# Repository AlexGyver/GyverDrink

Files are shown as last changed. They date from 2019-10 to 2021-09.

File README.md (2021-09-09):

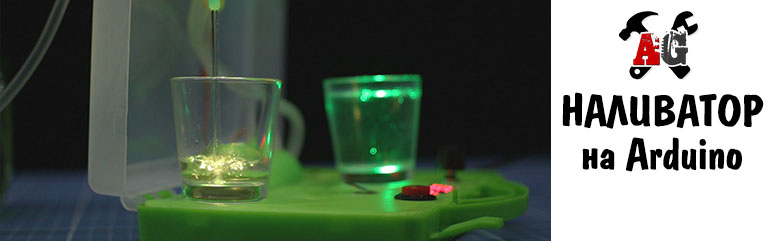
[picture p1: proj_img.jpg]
PROJECT_PHOTO

# Автоматический наливатор напитков на Arduino
* [Описание проекта](#chapter-0)
* [Папки проекта](#chapter-1)
* [Схемы подключения](#chapter-2)
* [Материалы и компоненты](#chapter-3)
* [Как скачать и прошить](#chapter-4)
* [FAQ](#chapter-5)
* [Полезная информация](#chapter-6)
AlexGyver YouTube (https://www.youtube.com/channel/UCgtAOyEQdAyjvm9ATCi_Aig?sub_confirmation=1)

## Описание проекта
Автоматический разливатор-дозатор напитков на Arduino:
- Сделан из чемоданчика - набора отвёрток из фикс-прайса
- Остальные компоненты тоже из фикс-прайса
- Электроника с Алиэкспресс
- Система рассчитана на 1-6 рюмок
- Подсветка рюмок:
	- Красный - пустая
	- Жёлтый - в процессе заполнения
	- Зелёный - готово к употреблению
- Надёжный механический датчик наличия рюмки
- Складная конструкция
- Пищевая мембранная помпа
- Энкодер, дисплей
- Страница проекта на сайте: https://alexgyver.ru/GyverDrink/
- **КРУТОЕ ОБНОВЛЕНИЕ ПРОЕКТА ОТ VICLER** https://github.com/VICLER/GyverDrink

## Папки
**ВНИМАНИЕ! Если это твой первый опыт работы с Arduino, читай [инструкцию](#chapter-4)**
- **libraries** - библиотеки проекта. Заменить имеющиеся версии
- **firmware** - прошивки для Arduino
- **schemes** - схемы подключения компонентов

## Схемы
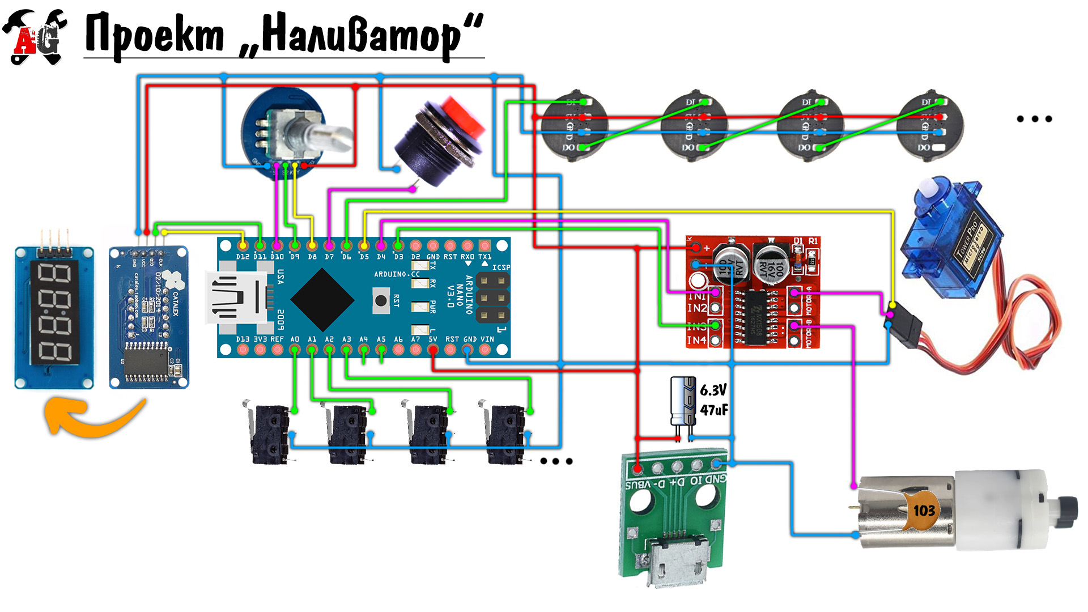
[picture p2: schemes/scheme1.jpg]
SCHEME

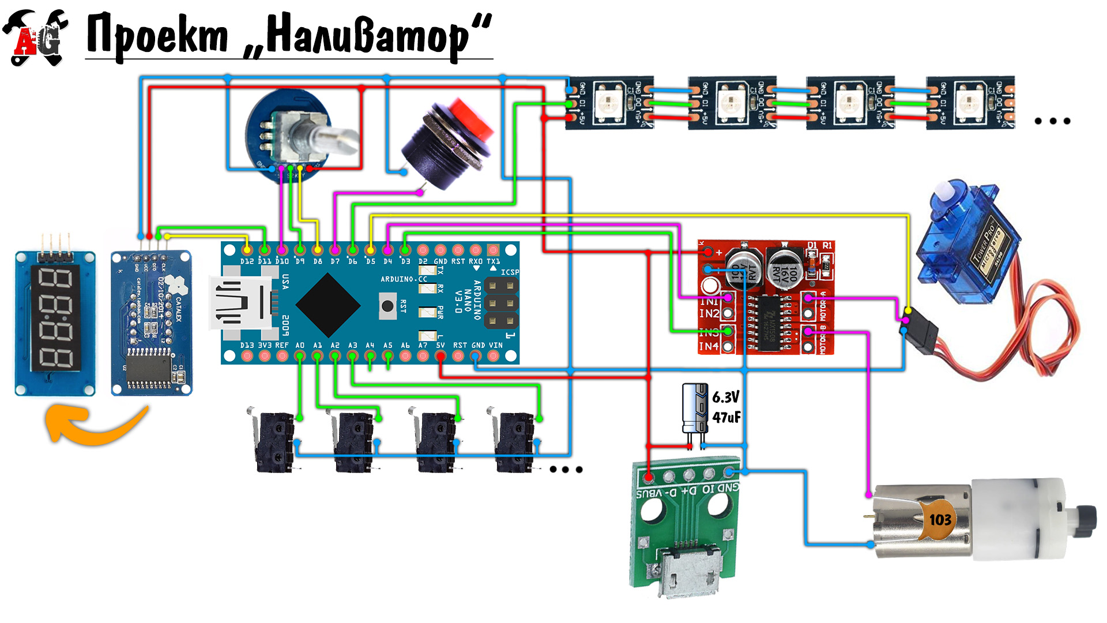
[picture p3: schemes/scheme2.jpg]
SCHEME


## Материалы и компоненты
### Ссылки оставлены на магазины, с которых я закупаюсь уже не один год
- Arduino NANO https://ali.ski/QeCP0t
- Адресная лента (под нарезку) https://ali.ski/jHiVH
- Адресные модули поштучно https://ali.ski/Fi_wm
- Энкодер https://ali.ski/LUPzE
- Кнопка https://ali.ski/25Ygho
- Дисплей https://ali.ski/a7zkbY
- Концевики https://ali.ski/24PWCi
- Драйвер https://ali.ski/31K2Pn
- Серво https://ali.ski/aizZQn
- Модуль USB https://ali.ski/P_Taq
- Помпа https://ali.ski/zetxb  https://ali.ski/TQYUbB

## Вам скорее всего пригодится
* [Всё для пайки (паяльники и примочки)](http://alexgyver.ru/all-for-soldering/)
* [Недорогие инструменты](http://alexgyver.ru/my_instruments/)
* [Все существующие модули и сенсоры Arduino](http://alexgyver.ru/arduino_shop/)
* [Электронные компоненты](http://alexgyver.ru/electronics/)
* [Аккумуляторы и зарядные модули](http://alexgyver.ru/18650/)

## Как скачать и прошить
* [Первые шаги с Arduino](http://alexgyver.ru/arduino-first/) - ультра подробная статья по началу работы с Ардуино, ознакомиться первым делом!
* Скачать архив с проектом
> На главной странице проекта (где ты читаешь этот текст) вверху справа зелёная кнопка **Clone or download**, вот её жми, там будет **Download ZIP**
* Установить библиотеки в  
`C:\Program Files (x86)\Arduino\libraries\` (Windows x64)  
`C:\Program Files\Arduino\libraries\` (Windows x86)
* **Подключить внешнее питание 5 Вольт**
* Подключить плату к компьютеру
* Файл/Настройки, вставить ссылку http://arduino.esp8266.com/stable/package_esp8266com_index.json в в текст-бокс для дополнительных ссылок для менеджера плат
* Открыть Инструменты/Плата/Менеджер плат…, найти esp8266 by ESP8266 Community, установить версию 2.5.0
* Открыть Инструменты, настроить Плату, Порт и другие параметры как на скриншоте
* Загрузить прошивку

## Настройки в коде

## FAQ
### Основные вопросы
В: Как скачать с этого грёбаного сайта?  
О: На главной странице проекта (где ты читаешь этот текст) вверху справа зелёная кнопка **Clone or download**, вот её жми, там будет **Download ZIP**

В: Скачался какой то файл .zip, куда его теперь?  
О: Это архив. Можно открыть стандартными средствами Windows, но думаю у всех на компьютере установлен WinRAR, архив нужно правой кнопкой и извлечь.

В: Я совсем новичок! Что мне делать с Ардуиной, где взять все программы?  
О: Читай и смотри видос http://alexgyver.ru/arduino-first/

В: Вылетает ошибка загрузки / компиляции!
О: Читай тут: https://alexgyver.ru/arduino-first/#step-5

В: Сколько стоит?  
О: Ничего не продаю.

### Вопросы по этому проекту

## Полезная информация
* [Мой сайт](http://alexgyver.ru/)
* [Основной YouTube канал](https://www.youtube.com/channel/UCgtAOyEQdAyjvm9ATCi_Aig?sub_confirmation=1)
* [YouTube канал про Arduino](https://www.youtube.com/channel/UC4axiS76D784-ofoTdo5zOA?sub_confirmation=1)
* [Мои видеоуроки по пайке](https://www.youtube.com/playlist?list=PLOT_HeyBraBuMIwfSYu7kCKXxQGsUKcqR)
* [Мои видеоуроки по Arduino](http://alexgyver.ru/arduino_lessons/)

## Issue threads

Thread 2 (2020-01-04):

Объявление define

Roman-RV78, 2020-01-04:
Доброго. Читаем описание библиотеки microLED с сайта alexgyver.ru , знаете такой)))).

> ВНИМАНИЕ! define настройки (ORDER_GRB и COLOR_DEBTH) делаются до подключения библиотеки!

>
Но вот уже третья версия прошивки наливатора, а воз и ныне там))). Люди наступают на грабли. Со старой версией библиотеки объявления  дефайнов после подключения библиотеки хоть как то работало, то с новой нет.

AlexGyver, 2020-01-04:
Ничего не понял. Все версии библиотеки и наливатора замечательно работают. Дефайн после подключения вообще не имеет смысла, можно просто его удалить

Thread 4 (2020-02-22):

Прокручивание энкодера

brudtek, 2020-02-22:
При повороте энкодера возникают ложные срабатывания поворота в другую сторону. Если использовать один энкодер, то это особо не заметно,  но мы собрали в одном корпусе два наливатора. Все компоненты продублированны и собраны зеркально, кроме органа управления (экран, энкодер, кнопка пуск). И тут проблема стала ощутима.
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

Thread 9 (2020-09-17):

проблема с компиляцией

mishanya878, 2020-09-17:
Доброго времени суток! вот такая вот проблема. не могу понять что ардуина от меня хочет.

In file included from C:\Arduino firmware\GyverDrink_v1.5\GyverDrink_v1.5.ino:69:0:
C:\Program Files (x86)\Arduino\libraries\microLED/microLED.h:58:1: warning: 'typedef' was ignored in this declaration
 typedef struct LEDdata {
 ^~~~~~~
C:\Arduino firmware\GyverDrink_v1.5\c_func.ino: In function 'void serviceMode()':
C:\Arduino firmware\GyverDrink_v1.5\c_func.ino:6:61: warning: invalid conversion from 'byte* {aka unsigned char*}' to 'int8_t* {aka signed char*}' [-fpermissive]
     disp.runningString(serviceText, sizeof(serviceText), 150);
                                                             ^
In file included from C:\Arduino firmware\GyverDrink_v1.5\GyverDrink_v1.5.ino:67:0:
C:\Program Files (x86)\Arduino\libraries\GyverTM1637/GyverTM1637.h:46:7: note:   initializing argument 1 of 'void GyverTM1637::runningString(int8_t*, byte, int)'
  void runningString(int8_t DispData[], byte amount, int delayMs);    // бегущая строка (array, sizeof(array), задержка в мс)
       ^~~~~~~~~~~~~

AlexGyver, 2020-09-17:
Привет, в чем компилируешь?

mishanya878, 2020-09-17:
привет в Arduino IDE 1.8.13

mishanya878, 2020-09-17:
было больше ошибок,  прописал color_debt 3. после этого стало как сейчас

AlexGyver, 2020-09-18:
Попробуй удалить ide вместе с папкой и поставить все по новой по инструкции

mishanya878, 2020-09-18:
Ок, спасибо попробую. О результатах отпишусь

mishanya878, 2020-09-18:
Все переустановил, тоже самое. Но наливатор работает) спасибо за помощь и за такие проекты))

VICLER, 2020-09-18:
Это не проблемы, а просто предупреждения компилятора о "возможных" ошибках.

AlexGyver, 2020-09-18:
А код в итоге загружается, или вылетает ошибка компиляции? Если загружается, то хер с ним)

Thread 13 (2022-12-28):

Сервомотор поворачивается рывками

Olejan, 2022-12-28:
Сервомотор поворачивается рывками, при этом разливая жидкость из трубки на поверхность наливатора. А в сервисном режиме, если крутануть резко энкодер, то серву начинает дёргать туда-сюда, пока она не доедет до заданной позиции. Использовал в проекте библиотеку ServoSmooth из архива, и новую - результат не меняется, только с новой библиотекой серво поворачивается медленней.
Игрался с настройками скорости и угла поворота - не помогает, всё равно поворачивает рывками и разбрызгивает жидкость по наливатору. Питание нормальное. Помпа потребляет 0,5 А - батарея тянет. Серво потребляет в несколько раз меньше.
Есть какие-то рекомендации по исправлению эфекта дёргания сервы? Понимаю, раз у вас работает, должно и у меня работать - ан нет.

На видео версия, адаптированная под двухстрочный индикатор.
Настройки серво из видео:
	// настройка серво
	,,,
	servoON();
	servo.attach(SERVO_PIN, 200/*600*/, 2800/*2400*/);
	if (INVERSE_SERVO) servo.setDirection(REVERSE);

	servo.write(0);
	delay(800);
	servo.setTargetDeg(0);
	servo.setSpeed(40);
	servo.setAccel(0.3);

https://user-images.githubusercontent.com/5707511/209798714-3084589e-ccb2-40e0-afc7-65a30ce1fccc.mp4

GyverLibs, 2022-12-28:
Очень странно, может серва бракованная

Olejan, 2022-12-28:
Да, действительно. Заменил серву и уменьшил диаметр трубки стяжкой - эффект разбрызгивания ушёл.
Прошу прощения за беспокойство и с наступающим Новым Годом!

GyverLibs, 2022-12-28:
С наступающим да)

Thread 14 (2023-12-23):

Максимальное количество стаканов.

MykhailoMelnik, 2023-12-23:
Здравствуйте. Хочу сделать такой на восемь стаканов. Но у меня не получается.
Возможно подскажите куда мне смотреть? Буду очень благодарен!
Я изменил в коде:
    #define NUM_SHOTS 8       // количество рюмок (оно же кол-во светодиодов и кнопок!)
    const byte shotPos[] = {25, 60, 95, 130, 165, 200, 235, 270};
    const byte SW_pins[] = {A0, A1, A2, A3, A4, A5, A6, A7};

GyverLibs, 2023-12-25:
Привет, на пинах a6 и a7 кнопки в текущей реализации программы работать не будут

MykhailoMelnik, 2023-12-25:
я прнял что не работают.)) а с чем это связано?)

GyverLibs, 2023-12-25:
С тем что эти пины не являются цифровыми пинами, там только АЦП

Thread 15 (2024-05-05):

Проблема с первым светодиодом

pmaksSamara, 2024-05-05:
Всем привет.
Не пойму в чем проблема. Использую библиотеку microLED. Сама прошивка версии 1.5. Использую SMD светодиоды WS2812B. При нажатии на 1 концевик первый светодиод кратковременно моргает красным и гаснет. В сервисном режиме при нажатии концевика часто моргает зеленым. При этом все остальные светодиоды четко отрабатывают. Почему именно первый себя так ведет?
При компиляции как у всех вылезают сооющения про typedef.

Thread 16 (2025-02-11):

прошивка не грузиться

sir90ha, 2025-02-11:
Arduino: 1.8.19 (Windows 10), Плата:"Arduino Nano, ATmega328P"

C:\Users\Admin\Desktop\firmware\GyverDrink_v1.5\GyverDrink_v1.5.ino:65:0: warning: "COLOR_DEBTH" redefined

 #define COLOR_DEBTH 2   // цветовая глубина: 1, 2, 3 (в байтах)

In file included from C:\Users\Admin\Desktop\firmware\GyverDrink_v1.5\GyverDrink_v1.5.ino:58:0:

C:\Users\Admin\Documents\Arduino\libraries\microLED\src/microLED.h:37:0: note: this is the location of the previous definition

 #define COLOR_DEBTH 3    // по умолчанию 24 бита

C:\Users\Admin\Desktop\firmware\GyverDrink_v1.5\GyverDrink_v1.5.ino:67:37: warning: invalid conversion from 'mData*' to 'uint8_t {aka unsigned char}' [-fpermissive]

 mData strip(leds, NUM_SHOTS, LED_PIN);  // объект лента

                                     ^

In file included from C:\Users\Admin\Documents\Arduino\libraries\microLED\src/microLED.h:41:0,

                 from C:\Users\Admin\Desktop\firmware\GyverDrink_v1.5\GyverDrink_v1.5.ino:58:

C:\Users\Admin\Documents\Arduino\libraries\microLED\src/color_utility.h:23:12: note:   initializing argument 1 of 'mData::mData(uint8_t, uint8_t, uint8_t)'

     inline mData(uint8_t _r, uint8_t _g, uint8_t _b) MICROLED_INLINE :r(_r), g(_g), b(_b) {}

            ^~~~~

C:\Users\Admin\Desktop\firmware\GyverDrink_v1.5\a_setup.ino: In function 'void setup()':

a_setup:14:9: error: 'struct mData' has no member named 'setBrightness'

   strip.setBrightness(130);

         ^~~~~~~~~~~~~

a_setup:15:9: error: 'struct mData' has no member named 'clear'

   strip.clear();

         ^~~~~

a_setup:16:9: error: 'struct mData' has no member named 'show'

   strip.show();

         ^~~~

C:\Users\Admin\Desktop\firmware\GyverDrink_v1.5\c_func.ino: In function 'void serviceMode()':

c_func:35:19: error: 'struct mData' has no member named 'setLED'

             strip.setLED(i, mCOLOR(GREEN));

                   ^~~~~~

c_func:35:36: error: 'GREEN' was not declared in this scope

             strip.setLED(i, mCOLOR(GREEN));

                                    ^~~~~

C:\Users\Admin\Desktop\firmware\GyverDrink_v1.5\c_func.ino:35:36: note: suggested alternative: 'SREG_N'

             strip.setLED(i, mCOLOR(GREEN));

                                    ^~~~~

                                    SREG_N

c_func:35:29: error: 'mCOLOR' was not declared in this scope

             strip.setLED(i, mCOLOR(GREEN));

                             ^~~~~~

C:\Users\Admin\Desktop\firmware\GyverDrink_v1.5\c_func.ino:35:29: note: suggested alternative: 'COLORS'

             strip.setLED(i, mCOLOR(GREEN));

                             ^~~~~~

                             COLORS

c_func:37:19: error: 'struct mData' has no member named 'setLED'

             strip.setLED(i, mCOLOR(BLACK));

                   ^~~~~~

c_func:37:36: error: 'BLACK' was not declared in this scope

             strip.setLED(i, mCOLOR(BLACK));

                                    ^~~~~

c_func:37:29: error: 'mCOLOR' was not declared in this scope

             strip.setLED(i, mCOLOR(BLACK));

                             ^~~~~~

C:\Users\Admin\Desktop\firmware\GyverDrink_v1.5\c_func.ino:37:29: note: suggested alternative: 'COLORS'

             strip.setLED(i, mCOLOR(BLACK));

                             ^~~~~~

                             COLORS

c_func:39:17: error: 'struct mData' has no member named 'show'

           strip.show();

                 ^~~~

C:\Users\Admin\Desktop\firmware\GyverDrink_v1.5\c_func.ino: In function 'void flowTick()':

c_func:86:15: error: 'struct mData' has no member named 'setLED'

         strip.setLED(i, mCOLOR(RED));                               // подсветили

               ^~~~~~

c_func:86:32: error: 'RED' was not declared in this scope

         strip.setLED(i, mCOLOR(RED));                               // подсветили

                                ^~~

C:\Users\Admin\Desktop\firmware\GyverDrink_v1.5\c_func.ino:86:32: note: suggested alternative: 'READY'

         strip.setLED(i, mCOLOR(RED));                               // подсветили

                                ^~~

                                READY

c_func:86:25: error: 'mCOLOR' was not declared in this scope

         strip.setLED(i, mCOLOR(RED));                               // подсветили

                         ^~~~~~

C:\Users\Admin\Desktop\firmware\GyverDrink_v1.5\c_func.ino:86:25: note: suggested alternative: 'COLORS'

         strip.setLED(i, mCOLOR(RED));                               // подсветили

                         ^~~~~~

                         COLORS

c_func:93:15: error: 'struct mData' has no member named 'setLED'

         strip.setLED(i, mCOLOR(BLACK));                             // нигра

               ^~~~~~

c_func:93:32: error: 'BLACK' was not declared in this scope

         strip.setLED(i, mCOLOR(BLACK));                             // нигра

                                ^~~~~

c_func:93:25: error: 'mCOLOR' was not declared in this scope

         strip.setLED(i, mCOLOR(BLACK));                             // нигра

                         ^~~~~~

C:\Users\Admin\Desktop\firmware\GyverDrink_v1.5\c_func.ino:93:25: note: suggested alternative: 'COLORS'

         strip.setLED(i, mCOLOR(BLACK));                             // нигра

                         ^~~~~~

                         COLORS

C:\Users\Admin\Desktop\firmware\GyverDrink_v1.5\c_func.ino: In function 'void flowRoutnie()':

c_func:154:13: error: 'struct mData' has no member named 'setLED'

       strip.setLED(curPumping, mCOLOR(YELLOW));           // зажгли цвет

             ^~~~~~

c_func:154:39: error: 'YELLOW' was not declared in this scope

       strip.setLED(curPumping, mCOLOR(YELLOW));           // зажгли цвет

                                       ^~~~~~

C:\Users\Admin\Desktop\firmware\GyverDrink_v1.5\c_func.ino:154:39: note: suggested alternative: 'LOW'

       strip.setLED(curPumping, mCOLOR(YELLOW));           // зажгли цвет

                                       ^~~~~~

                                       LOW

c_func:154:32: error: 'mCOLOR' was not declared in this scope

       strip.setLED(curPumping, mCOLOR(YELLOW));           // зажгли цвет

                                ^~~~~~

C:\Users\Admin\Desktop\firmware\GyverDrink_v1.5\c_func.ino:154:32: note: suggested alternative: 'COLORS'

       strip.setLED(curPumping, mCOLOR(YELLOW));           // зажгли цвет

                                ^~~~~~

                                COLORS

c_func:155:13: error: 'struct mData' has no member named 'show'

       strip.show();

             ^~~~

c_func:164:13: error: 'struct mData' has no member named 'setLED'

       strip.setLED(curPumping, mCOLOR(LIME));             // подсветили

             ^~~~~~

c_func:164:39: error: 'LIME' was not declared in this scope

       strip.setLED(curPumping, mCOLOR(LIME));             // подсветили

                                       ^~~~

C:\Users\Admin\Desktop\firmware\GyverDrink_v1.5\c_func.ino:164:39: note: suggested alternative: 'FILE'

       strip.setLED(curPumping, mCOLOR(LIME));             // подсветили

                                       ^~~~

                                       FILE

c_func:164:32: error: 'mCOLOR' was not declared in this scope

       strip.setLED(curPumping, mCOLOR(LIME));             // подсветили

                                ^~~~~~

C:\Users\Admin\Desktop\firmware\GyverDrink_v1.5\c_func.ino:164:32: note: suggested alternative: 'COLORS'

       strip.setLED(curPumping, mCOLOR(LIME));             // подсветили

                                ^~~~~~

                                COLORS

c_func:165:13: error: 'struct mData' has no member named 'show'

       strip.show();

             ^~~~

C:\Users\Admin\Desktop\firmware\GyverDrink_v1.5\c_func.ino: In function 'void LEDtick()':

c_func:184:11: error: 'struct mData' has no member named 'show'

     strip.show();

           ^~~~

exit status 1

'struct mData' has no member named 'setBrightness'

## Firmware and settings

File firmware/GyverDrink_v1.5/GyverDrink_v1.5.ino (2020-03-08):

/*
  Скетч к проекту "Наливатор by AlexGyver"
  - Страница проекта (схемы, описания): https://alexgyver.ru/GyverDrink/
  - Исходники на GitHub: https://github.com/AlexGyver/GyverDrink/
  Проблемы с загрузкой? Читай гайд для новичков: https://alexgyver.ru/arduino-first/
  Нравится, как написан код? Поддержи автора! https://alexgyver.ru/support_alex/
  Автор: AlexGyver, AlexGyver Technologies, 2019
  https://www.youtube.com/c/alexgyvershow
  https://github.com/AlexGyver
  https://AlexGyver.ru/
  alex@alexgyver.ru
*/

/*
   Версия 1.1:
   - Поправлена работа системы при выборе некорректного объёма
   - Исправлены ошибки при наливании больших объёмов
   - Исправлен баг с остановкой наливания при убирании другой рюмки

   Версия 1.2:
   - Исправлено ограничение выбора объёма
   - Исправлены ошибки (обновите библиотеки из архива! servoSmooth v1.8, microLED v2.3)
   - Добавлено хранение в памяти выбранного объёма

   Версия 1.3:
   - Исправлен баг со снятием рюмки в авто режиме (жука поймал Юрий Соколов)

   Версия 1.4:
   - Добавлена настройка уровня концевиков (для ИК датчиков)
   - Исправлена ошибка с наливанием больших объёмов

   Версия 1.5:
   - Добавлена инверсия сервопривода (ОБНОВИТЕ БИБЛИОТЕКУ ИЗ АРХИВА)
*/

// ======== НАСТРОЙКИ ========
#define NUM_SHOTS 4       // количество рюмок (оно же кол-во светодиодов и кнопок!)
#define TIMEOUT_OFF 5     // таймаут на выключение (перестаёт дёргать привод), минут
#define SWITCH_LEVEL 0    // кнопки 1 - высокий сигнал при замыкании, 0 - низкий
#define INVERSE_SERVO 0   // инвертировать направление вращения серво

// положение серво над центрами рюмок
const byte shotPos[] = {25, 60, 95, 145, 60, 60};

// время заполнения 50 мл
const long time50ml = 5500;

#define KEEP_POWER 1    // 1 - система поддержания питания ПБ, чтобы он не спал

// отладка
#define DEBUG_UART 1

// =========== ПИНЫ ===========
#define PUMP_POWER 3
#define SERVO_POWER 4
#define SERVO_PIN 5
#define LED_PIN 6
#define BTN_PIN 7
#define ENC_SW 8
#define ENC_DT 9
#define ENC_CLK 10
#define DISP_DIO 11
#define DISP_CLK 12
const byte SW_pins[] = {A0, A1, A2, A3, A4, A5};

// =========== ЛИБЫ ===========
#include <GyverTM1637.h>
#include <ServoSmooth.h>
#include <microLED.h>
#include <EEPROM.h>
#include "encUniversalMinim.h"
#include "buttonMinim.h"
#include "timer2Minim.h"

// =========== ДАТА ===========
#define COLOR_DEBTH 2   // цветовая глубина: 1, 2, 3 (в байтах)
LEDdata leds[NUM_SHOTS];  // буфер ленты типа LEDdata (размер зависит от COLOR_DEBTH)
microLED strip(leds, NUM_SHOTS, LED_PIN);  // объект лента

GyverTM1637 disp(DISP_CLK, DISP_DIO);

// пин clk, пин dt, пин sw, направление (0/1), тип (0/1)
encMinim enc(ENC_CLK, ENC_DT, ENC_SW, 1, 1);

ServoSmooth servo;

buttonMinim btn(BTN_PIN);
buttonMinim encBtn(ENC_SW);
timerMinim LEDtimer(100);
timerMinim FLOWdebounce(20);
timerMinim FLOWtimer(2000);
timerMinim WAITtimer(400);
timerMinim TIMEOUTtimer(15000);   // таймаут дёргания приводом
timerMinim POWEROFFtimer(TIMEOUT_OFF * 60000L);

bool LEDchanged = false;
bool pumping = false;
int8_t curPumping = -1;

enum {NO_GLASS, EMPTY, IN_PROCESS, READY} shotStates[NUM_SHOTS];
enum {SEARCH, MOVING, WAIT, PUMPING} systemState;
bool workMode = false;  // 0 manual, 1 auto
int thisVolume = 50;
bool systemON = false;
bool timeoutState = false;
bool volumeChanged = false;
bool parking = false;

// =========== МАКРО ===========
#define servoON() digitalWrite(SERVO_POWER, 1)
#define servoOFF() digitalWrite(SERVO_POWER, 0)
#define pumpON() digitalWrite(PUMP_POWER, 1)
#define pumpOFF() digitalWrite(PUMP_POWER, 0)

#if (DEBUG_UART == 1)
#define DEBUG(x) Serial.println(x)
#else
#define DEBUG(x)
#endif

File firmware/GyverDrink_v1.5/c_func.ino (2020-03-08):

// различные функции

void serviceMode() {
  if (!digitalRead(BTN_PIN)) {
    byte serviceText[] = {_S, _E, _r, _U, _i, _C, _E};
    disp.runningString(serviceText, sizeof(serviceText), 150);
    while (!digitalRead(BTN_PIN));  // ждём отпускания
    delay(200);
    servoON();
    int servoPos = 0;
    long pumpTime = 0;
    timerMinim timer100(100);
    disp.displayInt(0);
    bool flag;
    for (;;) {
      servo.tick();
      enc.tick();

      if (timer100.isReady()) {   // период 100 мс
        // работа помпы со счётчиком
        if (!digitalRead(ENC_SW)) {
          if (flag) pumpTime += 100;
          else pumpTime = 0;
          disp.displayInt(pumpTime);
          pumpON();
          flag = true;
        } else {
          pumpOFF();
          flag = false;
        }

        // зажигаем светодиоды от кнопок
        for (byte i = 0; i < NUM_SHOTS; i++) {
          if (!digitalRead(SW_pins[i])) {
            strip.setLED(i, mCOLOR(GREEN));
          } else {
            strip.setLED(i, mCOLOR(BLACK));
          }
          strip.show();
        }
      }

      if (enc.isTurn()) {
        // крутим серво от энкодера
        pumpTime = 0;
        if (enc.isLeft()) {
          servoPos += 5;
        }
        if (enc.isRight()) {
          servoPos -= 5;
        }
        servoPos = constrain(servoPos, 0, 180);
        disp.displayInt(servoPos);
        servo.setTargetDeg(servoPos);
      }

      if (btn.holded()) {
        servo.setTargetDeg(0);
        break;
      }
    }
  }
  disp.clear();
  while (!servo.tick());
  servoOFF();
}

// выводим объём и режим
void dispMode() {
  disp.displayInt(thisVolume);
  if (workMode) disp.displayByte(0, _A);
  else {
    disp.displayByte(0, _P);
    pumpOFF();
  }
}

// наливайка, опрос кнопок
void flowTick() {
  if (FLOWdebounce.isReady()) {
    for (byte i = 0; i < NUM_SHOTS; i++) {
      bool swState = !digitalRead(SW_pins[i]) ^ SWITCH_LEVEL;
      if (swState && shotStates[i] == NO_GLASS) {  // поставили пустую рюмку
        timeoutReset();                                             // сброс таймаута
        shotStates[i] = EMPTY;                                      // флаг на заправку
        strip.setLED(i, mCOLOR(RED));                               // подсветили
        LEDchanged = true;
        DEBUG("set glass");
        DEBUG(i);
      }
      if (!swState && shotStates[i] != NO_GLASS) {   // убрали пустую/полную рюмку
        shotStates[i] = NO_GLASS;                                   // статус - нет рюмки
        strip.setLED(i, mCOLOR(BLACK));                             // нигра
        LEDchanged = true;
        timeoutReset();                                             // сброс таймаута
        if (i == curPumping) {
          curPumping = -1; // снимаем выбор рюмки
          systemState = WAIT;                                       // режим работы - ждать
          WAITtimer.reset();
          pumpOFF();                                                // помпу выкл
        }
        DEBUG("take glass");
        DEBUG(i);
      }
    }

    if (workMode) {         // авто
      flowRoutnie();        // крутим отработку кнопок и поиск рюмок
    } else {                // ручной
      if (btn.clicked()) {  // клик!
        systemON = true;    // система активирована
        timeoutReset();     // таймаут сброшен
      }
      if (systemON) flowRoutnie();  // если активны - ищем рюмки и всё такое
    }
  }
}

// поиск и заливка
void flowRoutnie() {
  if (systemState == SEARCH) {                            // если поиск рюмки
    bool noGlass = true;
    for (byte i = 0; i < NUM_SHOTS; i++) {
      if (shotStates[i] == EMPTY && i != curPumping) {    // поиск
        noGlass = false;                                  // флаг что нашли хоть одну рюмку
        parking = false;
        curPumping = i;                                   // запоминаем выбор
        systemState = MOVING;                             // режим - движение
        shotStates[curPumping] = IN_PROCESS;              // стакан в режиме заполнения
        servoON();                                        // вкл питание серво
        servo.attach();
        servo.setTargetDeg(shotPos[curPumping]);          // задаём цель
        DEBUG("find glass");
        DEBUG(curPumping);
        break;
      }
    }
    if (noGlass && !parking) {                            // если не нашли ни одной рюмки
      servoON();
      servo.setTargetDeg(0);                              // цель серво - 0
      if (servo.tick()) {                                 // едем до упора
        servoOFF();                                       // выключили серво
        systemON = false;                                 // выключили систему
        parking = true;
        DEBUG("no glass");        
      }
    }
  } else if (systemState == MOVING) {                     // движение к рюмке
    if (servo.tick()) {                                   // если приехали
      systemState = PUMPING;                              // режим - наливание
      FLOWtimer.setInterval((long)thisVolume * time50ml / 50);  // перенастроили таймер
      FLOWtimer.reset();                                  // сброс таймера
      pumpON();                                           // НАЛИВАЙ!
      strip.setLED(curPumping, mCOLOR(YELLOW));           // зажгли цвет
      strip.show();
      DEBUG("fill glass");
      DEBUG(curPumping);
    }

  } else if (systemState == PUMPING) {                    // если качаем
    if (FLOWtimer.isReady()) {                            // если налили (таймер)
      pumpOFF();                                          // помпа выкл
      shotStates[curPumping] = READY;                     // налитая рюмка, статус: готов
      strip.setLED(curPumping, mCOLOR(LIME));             // подсветили
      strip.show();
      curPumping = -1;                                    // снимаем выбор рюмки
      systemState = WAIT;                                 // режим работы - ждать
      WAITtimer.reset();
      DEBUG("wait");
    }
  } else if (systemState == WAIT) {
    if (WAITtimer.isReady()) {                            // подождали после наливания
      systemState = SEARCH;
      timeoutReset();
      DEBUG("search");
    }
  }
}

// отрисовка светодиодов по флагу (100мс)
void LEDtick() {
  if (LEDchanged && LEDtimer.isReady()) {
    LEDchanged = false;
    strip.show();
  }
}

// сброс таймаута
void timeoutReset() {
  if (!timeoutState) disp.brightness(7);
  timeoutState = true;
  TIMEOUTtimer.reset();
  TIMEOUTtimer.start();
  DEBUG("timeout reset");
}
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

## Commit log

2020-03-25 adopt for Stepper
2020-03-26 Stepper integration
2020-03-26 update
    homing speed reducing to 1/2
2020-03-26 update
    homing speed
2020-04-05 upd
    fix first homing direction
    [a_setup.ino]
2020-04-07 upd
    disp.clear() bug fixed
    [a_setup.ino, c_func.ino]
2020-04-16 upd
    фикс самой первой прокачки после включения
2020-05-12 upd12.05.2020
    bug fixed:
    infinite loop on start with no STEPPER_ENDSTOP defined
    [a_setup.ino]
2020-05-15 upd 15.05.2020
    bug fixes
    [a_setup.ino, c_func.ino]
2020-05-15 15.05.2020
    bug fixes. StepMot v1.7 required
    [c_func.ino]
2020-05-16 upd 16.05.2020
    STEPPER_ENDSTOP pin changed for Arduino Nano
2020-05-19 upd 19.05.2020
    timer bug fix:
    system stopped after filling first shot
    [c_func.ino]
2020-05-20 upd v1.8
    standby lights
    bugfixes
    [a_setup.ino, c_func.ino]
2020-05-25 Update ServoSmooth.cpp
    Исправление ошибки неправильного поведения при инверсии сервопривода
2020-05-26 ServoSmooth v2.2
2020-07-14 upd 1.9
    added MAX_VOLUME
    fix no moving if first shot equals parking position
    [c_func.ino]
